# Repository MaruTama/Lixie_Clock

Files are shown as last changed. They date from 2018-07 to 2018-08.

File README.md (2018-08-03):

# Lixie Clock
What is the Lixie ?  
Lixie is a display unit using acrylic board like Nixie Tube.

# Other
表示器のグリッドは0.05mmで作成している

# Using libraries
[kicad_ArduinoNano](https://github.com/kiwichrish/kicad_ArduinoNano)
https://forum.kicad.info/t/where-are-the-momentary-bush-button-switches-located/5695
[Tiny_RTC](https://www.elecrow.com/wiki/index.php?title=Tiny_RTC)
[DateTime](http://playground.arduino.cc/Code/DateTime)

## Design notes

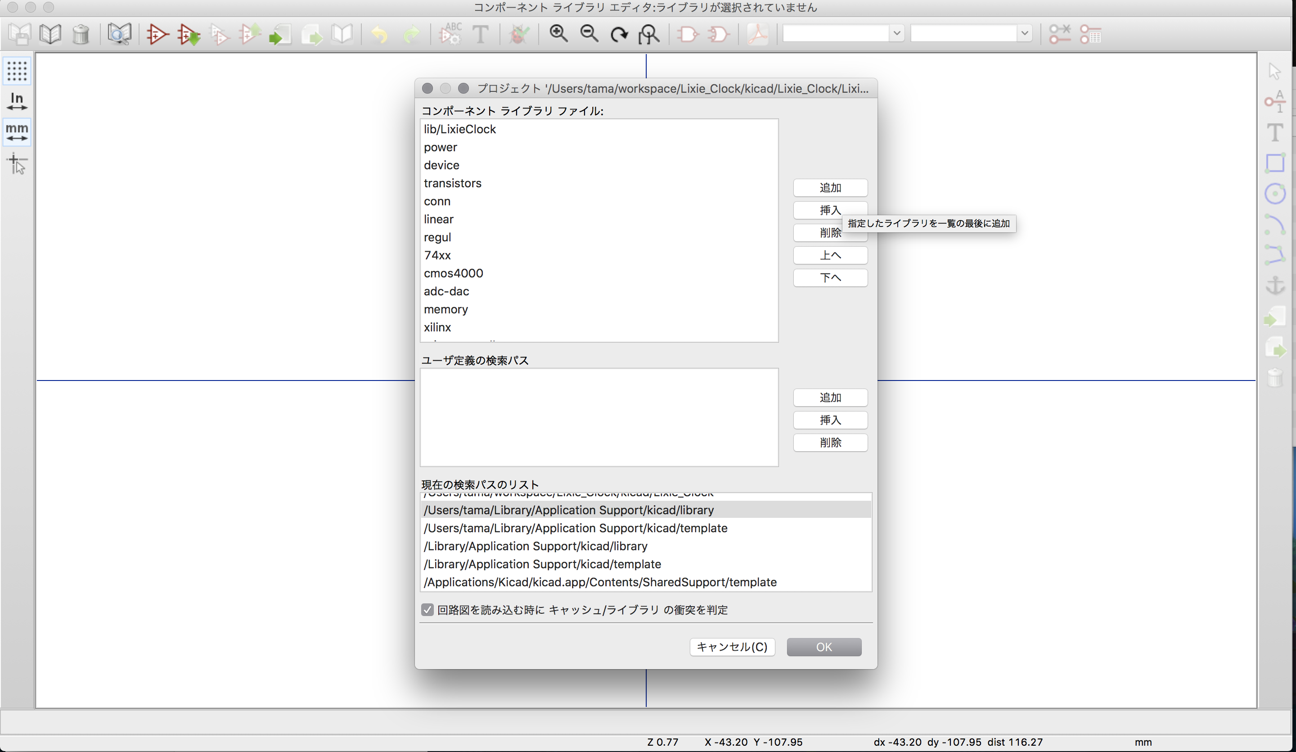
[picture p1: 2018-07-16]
kicad/img/スクリーンショット 2018-07-16 00.18.22.png

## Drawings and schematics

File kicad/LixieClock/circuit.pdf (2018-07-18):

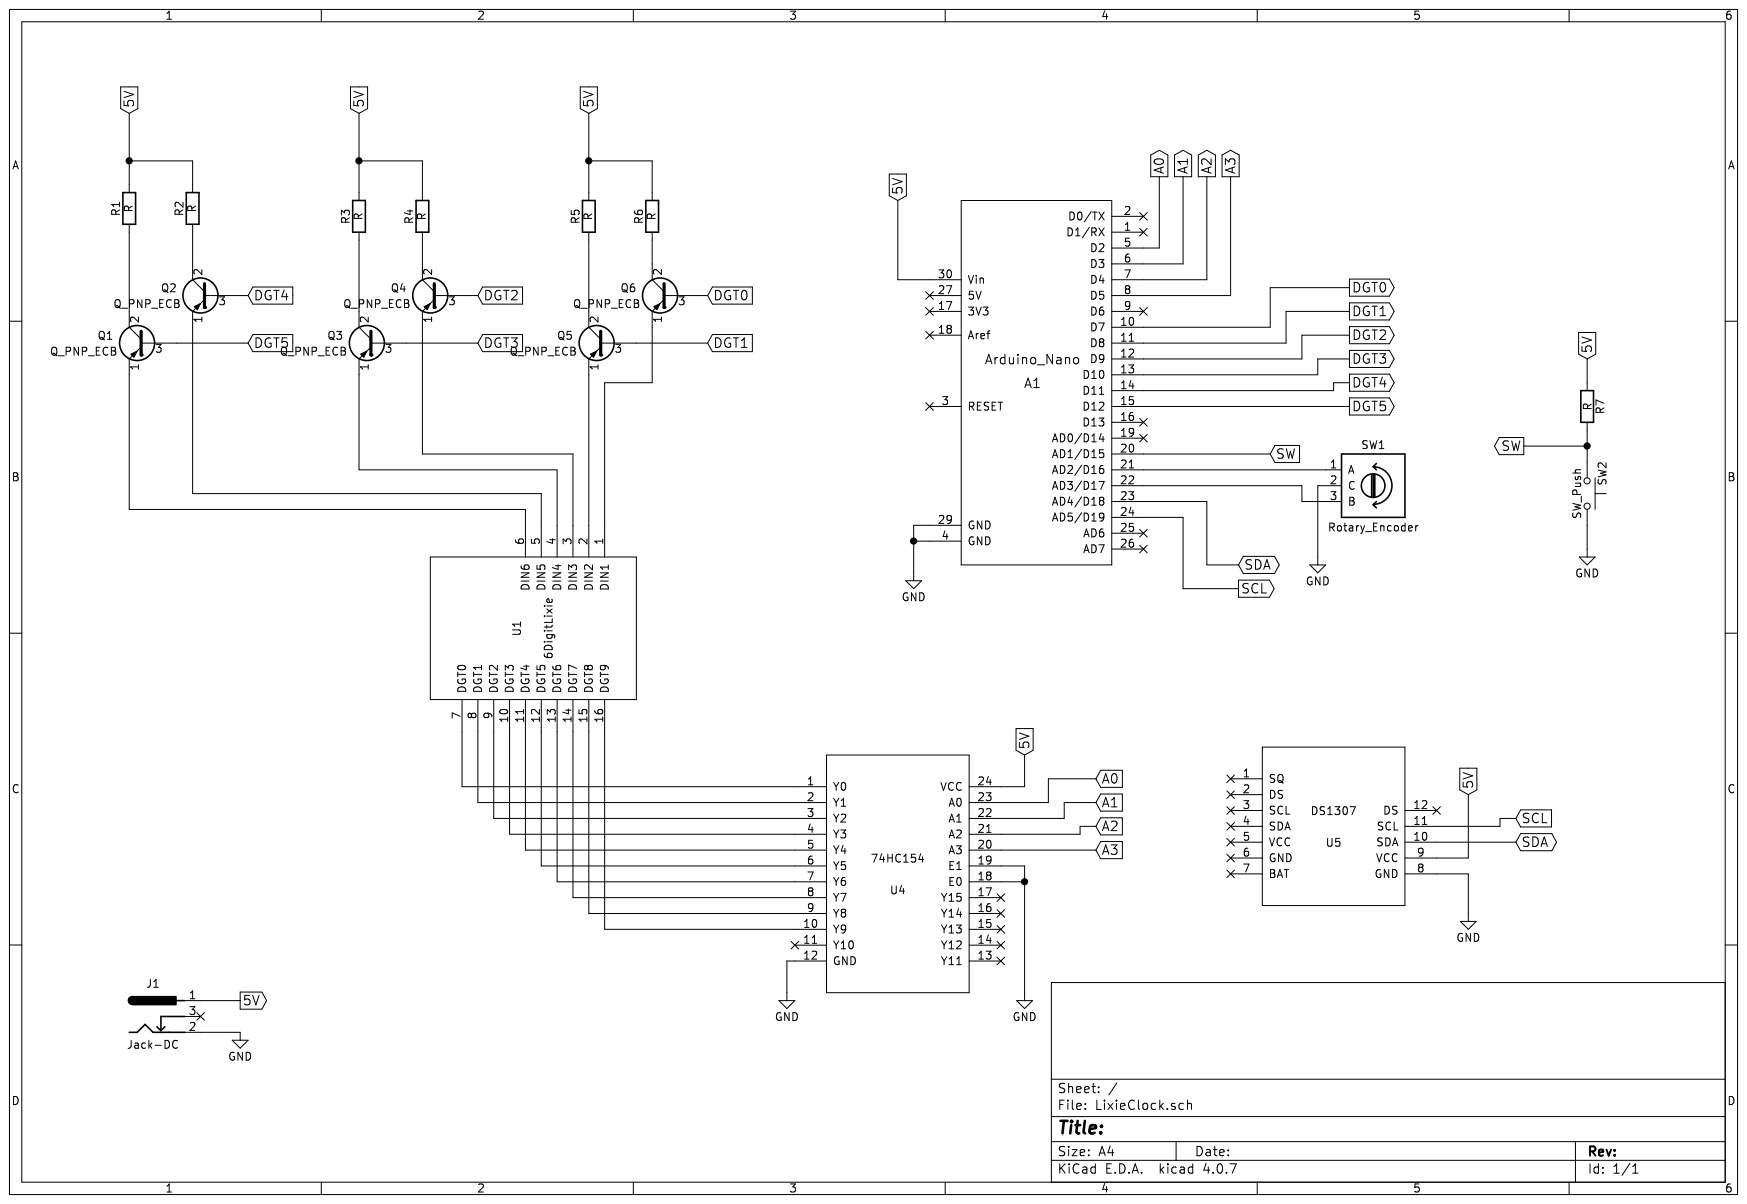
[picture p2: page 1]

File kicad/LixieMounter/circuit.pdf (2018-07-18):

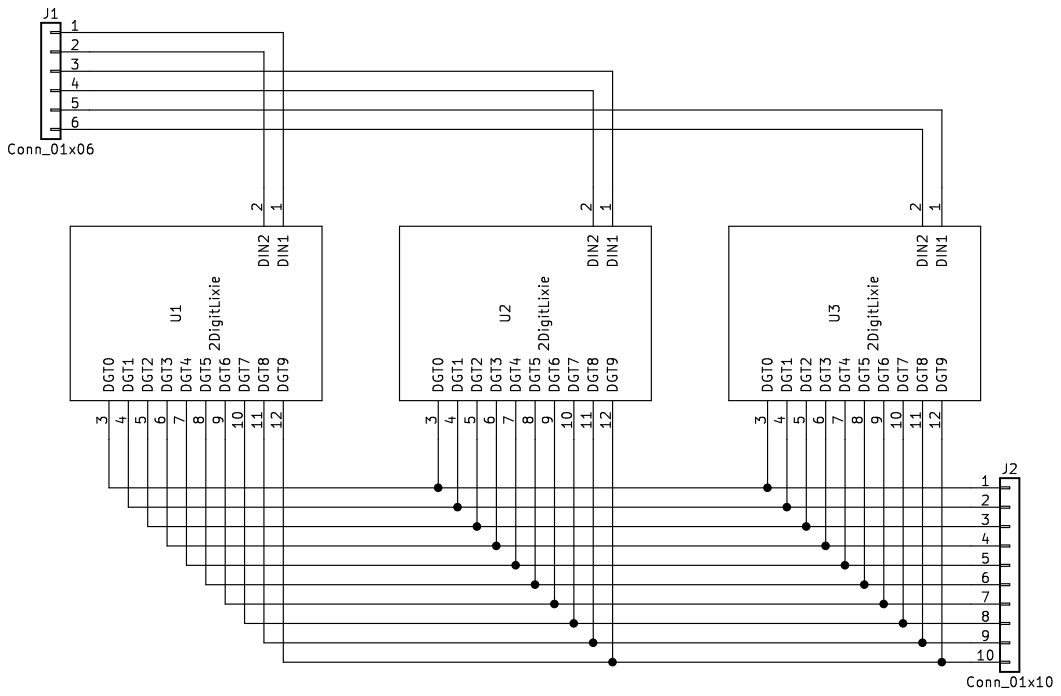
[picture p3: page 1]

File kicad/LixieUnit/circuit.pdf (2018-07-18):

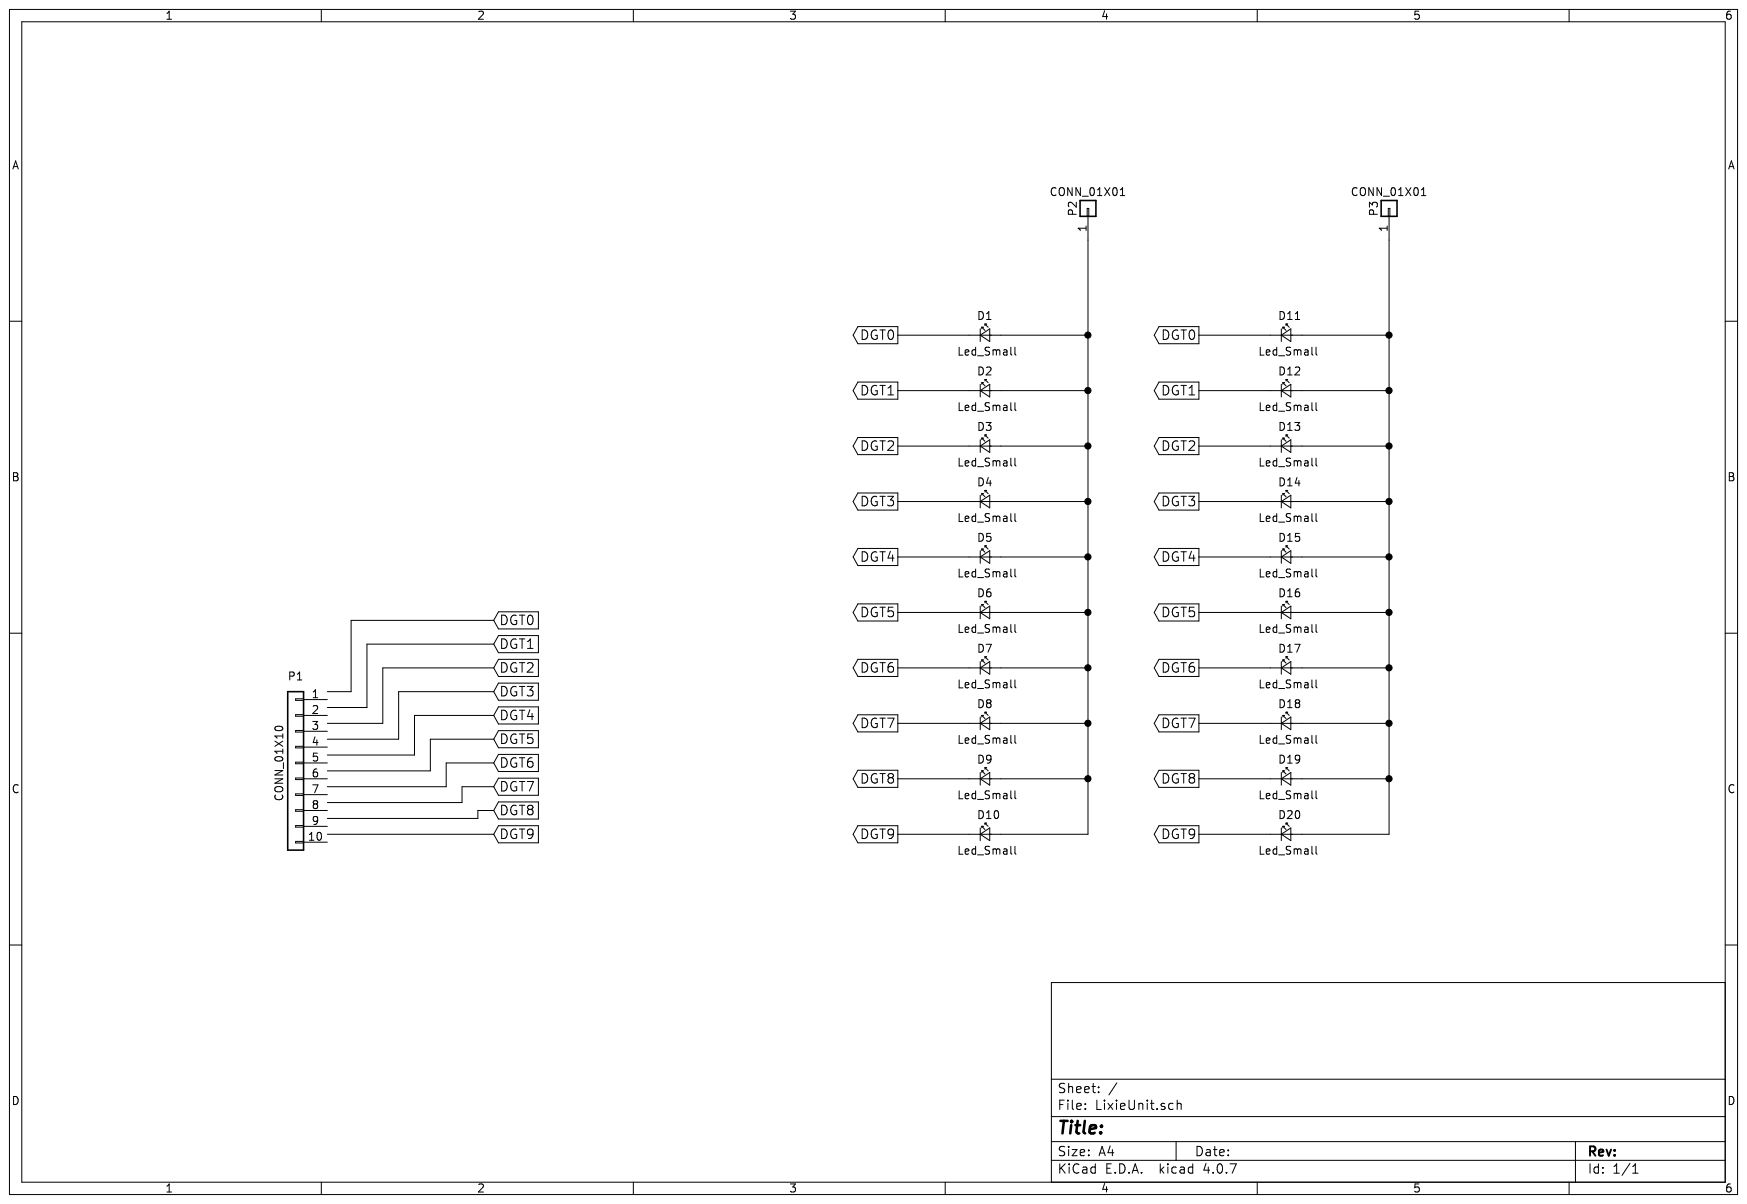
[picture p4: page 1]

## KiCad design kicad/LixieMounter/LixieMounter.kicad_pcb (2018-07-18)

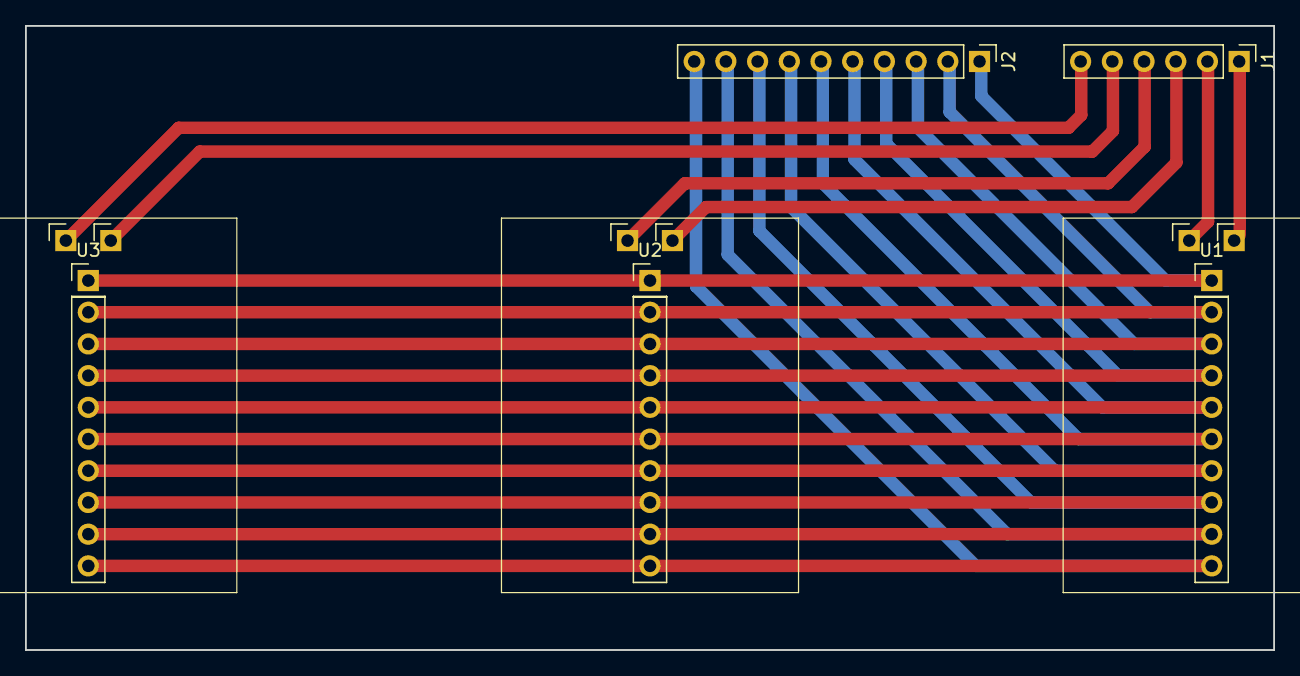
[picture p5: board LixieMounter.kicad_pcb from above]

Board: 2 copper layers, 100.0 x 50.0 mm, 5 parts (0 on the bottom side), 16 nets.

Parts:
J1: Conn_01x06; Socket_Strip_Straight_1x06_Pitch2.54mm
J2: Conn_01x10; Socket_Strip_Straight_1x10_Pitch2.54mm
U1, U2, U3: 2DigitLixie; LixieUnit

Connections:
unnamed: J1.1, U1.1
unnamed: J1.2, U1.2
unnamed: J1.3, U2.1
unnamed: J1.4, U2.2
unnamed: J1.5, U3.1
unnamed: J1.6, U3.2
unnamed: J2.1, U1.3, U2.3, U3.3
unnamed: J2.2, U1.4, U2.4, U3.4
unnamed: J2.3, U1.5, U2.5, U3.5
unnamed: J2.4, U1.6, U2.6, U3.6
unnamed: J2.5, U1.7, U2.7, U3.7
unnamed: J2.6, U1.8, U2.8, U3.8
unnamed: J2.7, U1.9, U2.9, U3.9
unnamed: J2.8, U1.10, U2.10, U3.10
unnamed: J2.9, U1.11, U2.11, U3.11
unnamed: J2.10, U1.12, U2.12, U3.12

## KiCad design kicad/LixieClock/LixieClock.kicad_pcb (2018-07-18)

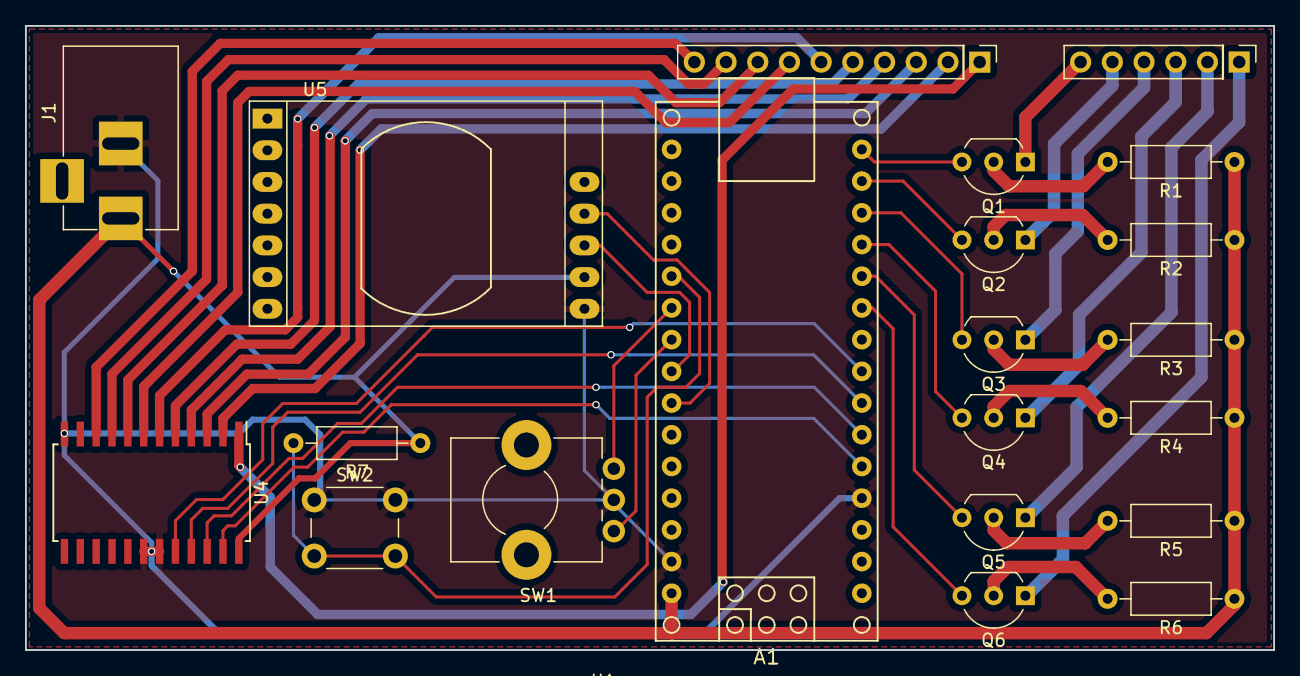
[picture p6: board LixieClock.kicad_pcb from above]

Board: 2 copper layers, 100.0 x 50.0 mm, 20 parts (0 on the bottom side), 39 nets.

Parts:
A1: Arduino_Nano; arduino_nano
J1: Jack-DC; BARREL_JACK
Q1, Q2, Q3, Q4, Q5, Q6: Q_PNP_ECB; TO-92_Inline_Wide
R1, R2, R3, R4, R5, R6, R7: R; R_Axial_DIN0207_L6.3mm_D2.5mm_P10.16mm_Horizontal
SW1: Rotary_Encoder; Potentiometer_Alps_RK09K_Horizontal
SW2: SW_Push; SW_PUSH_6mm_h7.3mm
U1: 6DigitLixie
U4: 74HC154; SOIC-24W_7.5x15.4mm_Pitch1.27mm
U5: DS1307; DS1307_Socket_LongPads

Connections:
5V: A1.30, J1.1, R1.1, R2.1, R3.1, R4.1, R5.1, R6.1, R7.1, U4.24, U5.9
A0: A1.5, U4.23
A1: A1.6, U4.22
A2: A1.7, U4.21
A3: A1.8, U4.20
DGT0: A1.10, Q6.3
DGT1: A1.11, Q5.3
DGT2: A1.12, Q4.3
DGT3: A1.13, Q3.3
DGT4: A1.14, Q2.3
DGT5: A1.15, Q1.3
GND: A1.4, A1.29, J1.2, SW1.2, SW2.1, U4.12, U4.18, U4.19, U5.8
unnamed: A1.21, SW1.1
unnamed: A1.22, SW1.3
unnamed: Q1.1, U1.6
unnamed: Q1.2, R1.2
unnamed: Q2.1, U1.5
unnamed: Q2.2, R2.2
unnamed: Q3.1, U1.4
unnamed: Q3.2, R3.2
unnamed: Q4.1, U1.3
unnamed: Q4.2, R4.2
unnamed: Q5.1, U1.2
unnamed: Q5.2, R5.2
unnamed: Q6.1, U1.1
unnamed: Q6.2, R6.2
unnamed: U1.7, U4.1
unnamed: U1.8, U4.2
unnamed: U1.9, U4.3
unnamed: U1.10, U4.4
unnamed: U1.11, U4.5
unnamed: U1.12, U4.6
unnamed: U1.13, U4.7
unnamed: U1.14, U4.8
unnamed: U1.15, U4.9
unnamed: U1.16, U4.10
SCL: A1.24, U5.11
SDA: A1.23, U5.10
SW: A1.20, R7.2, SW2.2

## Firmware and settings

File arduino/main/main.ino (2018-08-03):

/*
 * @Author     : MaruTama
 * @LastUpdate : 2018/08/02
 * @Since      : 2018/07/26
 * 
 * @reference
 * [Arduinoでロータリーエンコーダー](https://jiwashin.blogspot.com/2016/12/rotery-encoder-and-arduino.html)
 * [Arduinoでロータリーエンコーダを使いたい話](https://qiita.com/trancingyou/items/4c0504604bab3efcd6f1)
 * [ロータリーエンコーダを使う part 1 : 外部割込みとチャタリング対策](https://jumbleat.com/2016/12/17/encoder_1/)
 */

// 数字の変化させる方向
int const NUM_UP   = 0;
int const NUM_DOWN = 1;

//ピン番号宣言
int const TCT_SW = 15;
int const ENC_A  = 16;
int const ENC_B  = 17;

//変数の宣言
byte valSw;
bool isPushedSw = false;
byte valEnc;

bool isSetMode = false; // 時間設定モードであるか
int nowSettingDigit; // 今、時間設定している桁

// 初期化
void setup(void){
  pinMode(TCT_SW, INPUT);
  pinMode(ENC_A,INPUT_PULLUP);
  pinMode(ENC_B,INPUT_PULLUP);
  Serial.begin(9600);
  RTC_init(); // RTC の初期化
  display_init(); // Lixie の表示の設定を行う
}


// 基本的にボタンとロータリーエンコーダの制御を行う
void loop(void){

  // 時刻取得
  getTime();

 /********************************************************
  * タクトスイッチに関する処理 
  ********************************************************/
  // チャタリングを防ぐために状態を byte 型 で状態変化を保持する
  if(digitalRead(TCT_SW) == 0){
        valSw = valSw<<1;
        valSw += digitalRead(TCT_SW);
        
  }else{
    //押されてなければ初期化
    valSw = 0xff; 
    isPushedSw = false;
  }
  // チャタリングが収まった
  if(valSw == 0x00 && !isPushedSw){
    isPushedSw = true;
    
    // 時間設定モードであるとき
    if(isSetMode){
      if(nowSettingDigit == 12){
        // RTCに時刻を送信する
        isSetMode  = false;
      }
      else{
        nowSettingDigit++;
      }
    }
    // 通常表示 -> 時間設定モードになったとき
    else{
      isSetMode  = true;
      nowSettingDigit = 7;
    }
  }

  
 /********************************************************
  * ロータリーエンコーダに関する処理
  ********************************************************/
  valEnc = valEnc<<2 & B00001100;
  valEnc += (digitalRead(ENC_A)<<1) + (digitalRead(ENC_B));
  /*
   * 次のように変化する.
   * L : 0100 <- 1101 <- 1011 <- 0010 <- 0000
   * R : 0000 -> 0001 -> 0111 -> 1110 -> 1000
   * 今回は、1クリック 4パルスのロータリーエンコーダなので
   * L : 0100
   * R : 1000
   * で判定できる
   */
  switch(valEnc){
    // 時計回り
    case B00000100 :
      Serial.println("Clockwise ");   
      break;

    // 反時計回り
    case B00001000 : 
      Serial.println("revarse ");  
      break;

    default: 
      break;
  }
}
/********************************************************
  * 時刻設定で各時間を調整する関数
  * @param digit : 設定中の桁 
  ********************************************************/
//void setTimes(int digit, int changeDirction){
//  // 時間設定中
//  if(isSetMode){
//    switch(digit){
//      case HOUR_OF_TEN_DIGIT:
//        if(changeDirction == NUM_UP)   time.hourOfTenDigit++;
//        if(changeDirction == NUM_DOWN) time.hourOfOneDigit--;
//        break;
//      case HOUR_OF_ONE_DIGIT:
//        break;
//      case MIN_OF_TEN_DIGIT:
//        break;
//      case MIN_OF_ONE_DIGIT:
//        break;
//      case SEC_OF_TEN_DIGIT:
//        break;
//      case SEC_OF_ONE_DIGIT:
//        break;
//    }
//  }
//}

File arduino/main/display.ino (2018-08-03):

#include <MsTimer2.h>

// 割込み周期 [ms]
int const INTERVAL = 2;

// 時間設定中に点滅する周期 [ms]
int const FLASH_INTERVAL = 200;

// 時間設定モードでの点滅のためのカウンタ
int count4flash = 0;

// ダイナミック点灯方式での桁の制御
int const HOUR_OF_TEN_DIGIT = 12;
int const HOUR_OF_ONE_DIGIT = 11;
int const MIN_OF_TEN_DIGIT  = 10;
int const MIN_OF_ONE_DIGIT  =  9;
int const SEC_OF_TEN_DIGIT  =  8;
int const SEC_OF_ONE_DIGIT  =  7;

// デコーダに渡す信号線
int const SGL0 = 5; // 2^3 の桁
int const SGL1 = 4; // 2^2 の桁
int const SGL2 = 3; // 2^1 の桁
int const SGL3 = 2; // 2^0 の桁



// LEDの位置とデコーダの出力が逆になっている。(0 で一番奥が光る。)
// そのため、プログラムで反転させる
int signalData[10][4] = 
                    {{1,0,0,1}, 
                     {1,0,0,0}, 
                     {0,1,1,1},
                     {0,1,1,0},
                     {0,1,0,1},
                     {0,1,0,0},
                     {0,0,1,1},
                     {0,0,1,0},
                     {0,0,0,1},
                     {0,0,0,0}};

int nowControlDigit; // 今、表示制御している桁


// ダイナミック点灯の制御を行う
void display_init(){
  pinMode(SGL0, OUTPUT);
  pinMode(SGL1, OUTPUT);
  pinMode(SGL2, OUTPUT);
  pinMode(SGL3, OUTPUT);
  
  pinMode(HOUR_OF_TEN_DIGIT, OUTPUT);
  pinMode(HOUR_OF_ONE_DIGIT, OUTPUT);
  pinMode(MIN_OF_TEN_DIGIT, OUTPUT);
  pinMode(MIN_OF_ONE_DIGIT, OUTPUT);
  pinMode(SEC_OF_TEN_DIGIT, OUTPUT);
  pinMode(SEC_OF_ONE_DIGIT, OUTPUT);

  // hour (左端)から制御する
  nowControlDigit = HOUR_OF_TEN_DIGIT;

  MsTimer2::set(INTERVAL, display);
  MsTimer2::start(); // タイマー割り込み開始
}

// 割り込み時に処理される関数
void display() {
  int num; 
  
  switch(nowControlDigit){
      case HOUR_OF_TEN_DIGIT:
        num = (int) time.hourOfTenDigit;
        break;
      case HOUR_OF_ONE_DIGIT:
        num = (int) time.hourOfOneDigit;
        break;
      case MIN_OF_TEN_DIGIT:
        num = (int) time.minOfTenDigit;
        break;
      case MIN_OF_ONE_DIGIT:
        num = (int) time.minOfOneDigit;
        break;
      case SEC_OF_TEN_DIGIT:
        num = (int) time.secOfTenDigit;
        break;
      case SEC_OF_ONE_DIGIT:
        num = (int) time.secOfOneDigit;
        break;
    }

  // すべてOFFにする
  digitalWrite(HOUR_OF_TEN_DIGIT, HIGH);
  digitalWrite(HOUR_OF_ONE_DIGIT, HIGH);
  digitalWrite(MIN_OF_TEN_DIGIT, HIGH);
  digitalWrite(MIN_OF_ONE_DIGIT, HIGH);
  digitalWrite(SEC_OF_TEN_DIGIT, HIGH);
  digitalWrite(SEC_OF_ONE_DIGIT, HIGH);
  
  // 表示させる数値をデコーダにセットする
  digitalWrite(SGL0, signalData[num][0]);
  digitalWrite(SGL1, signalData[num][1]);
  digitalWrite(SGL2, signalData[num][2]);
  digitalWrite(SGL3, signalData[num][3]);

  // 時刻設定中であるとき
  if(isSetMode){
    // 設定中の桁だけ点滅させる
    if(nowSettingDigit == nowControlDigit){
      // カウントの前半は点灯。後半は消灯
      if(count4flash < (FLASH_INTERVAL / INTERVAL)/2){
        // 表示させる桁をONにする
        digitalWrite(nowControlDigit, LOW);
      }
      count4flash++;
      if(count4flash > (FLASH_INTERVAL / INTERVAL)) count4flash = 0;
    }
    // 設定中以外の桁は通常表示
    else{
      digitalWrite(nowControlDigit, LOW);
    }
  }
  // 通常表示モード
  else{
    // 表示させる桁をONにする
    digitalWrite(nowControlDigit, LOW);
  }
  
  // 右端まで到達したので左端に戻す
  if(nowControlDigit == SEC_OF_ONE_DIGIT) nowControlDigit = HOUR_OF_TEN_DIGIT;
  else nowControlDigit--;

  // 時間取得(RTCから)の周期を作るためのカウンタ
  count4sec++;
}

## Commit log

2018-07-15 表示機のパターンを引き終えた
    [LixieUnit.kicad_pcb, LixieUnit.sch]
2018-07-16 回路図のコンポーネントを作成、配置した。
    [LixieClock.kicad_pcb, LixieClock.sch, LixieUnit.kicad_pcb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]
2018-07-16 面付け基板にした。また、面付けの場合、配線が恥から0.4mm以上離れてなければならないので離した。
    [LixieUnit.kicad_pcb]
2018-07-16 時計の回路を書き終えた
    [LixieClock.sch, LixieUnit.kicad_pcb]
2018-07-16 PCB上のフットプリントのコンポーネントを作成し、配置した。
    [LixieClock.kicad_pcb, LixieClock.sch]
2018-07-18 100×100mmのサイズに収めるにはちょっと無理があったので、LixieUnit <-> Mounter <-> MainBoardという3層構造に変更した。
    [LixieClock.kicad_pcb, LixieClock.sch, LixieMounter.kicad_pcb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]
2018-07-18 自動配線後、手作業で引き直し中
    [LixieClock.kicad_pcb]
2018-07-18 暫定的な基板の完成
    [LixieClock.kicad_pcb, LixieClock.sch, LixieMounter.kicad_pcb]
2018-08-02 ロータリーエンコーダが使えるようになった。
2018-08-02 タクトスイッチの入力を検出できるようになった。チャタリングへの対応も行った。
2018-08-02 RTCが使えることを確認した
2018-08-03 LEDの表示制御と時間設定が行えるようになった
